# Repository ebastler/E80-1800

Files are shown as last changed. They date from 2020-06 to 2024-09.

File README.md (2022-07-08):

# E80-1800
QMK compatible USB-C PCB for a Cherry G80-1800

The board has been prototyped and works as intended, while fitting most G80-1800 housings. Rev 1.1 and later should fix all tolerance issues, and fit all G80-1800 (and as far as I know also G81-1800) enclosures. I can, however, not guarantee perfect operation of the PCB or compatibility with every enclosure variation - if you encounter any issues, please let me know. Rev 1.2 has not yet been tested, but changes were minimal - no issues are to be expected. Stock situations as well as component rotations at JLC may change over time and hence I can not guarantee for the BOM/CPL files to work perfectly. Please double-check before ordering!

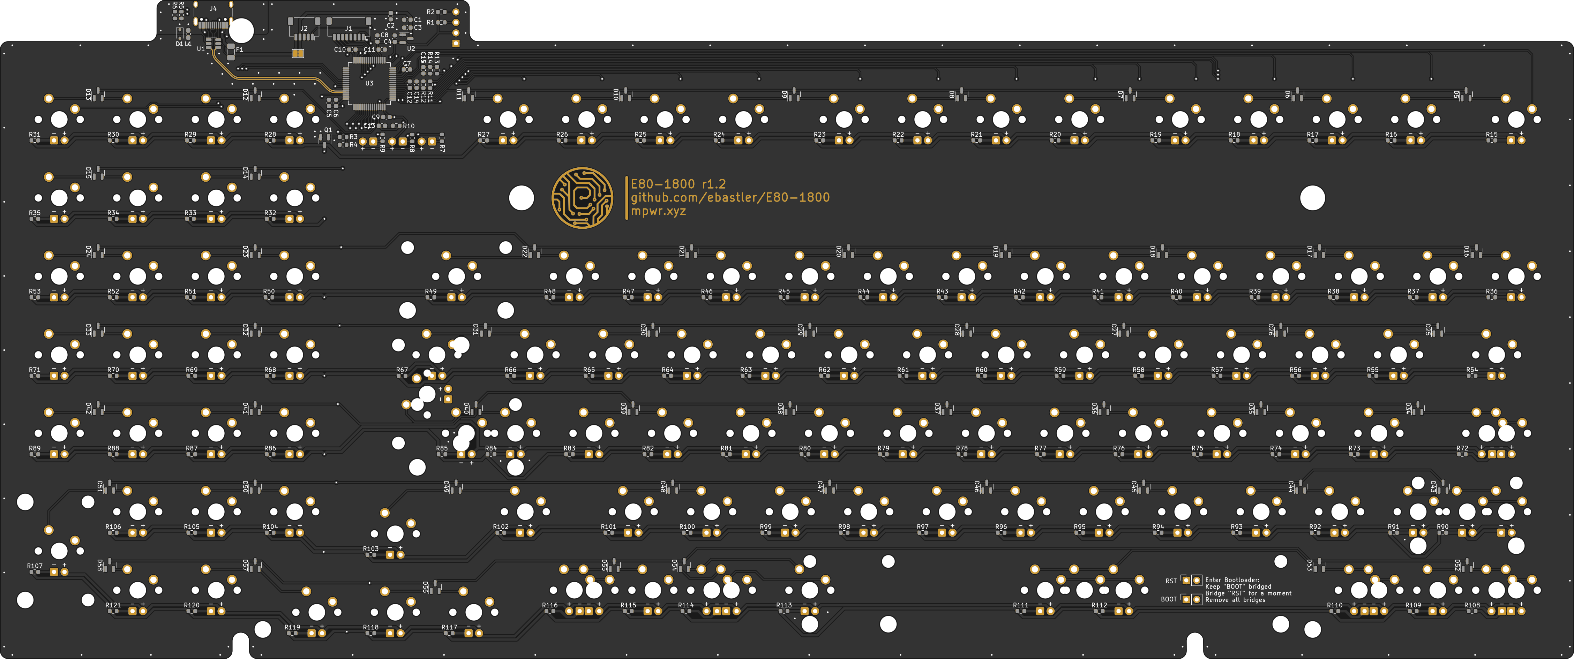
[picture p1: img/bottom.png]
pcb_bottom
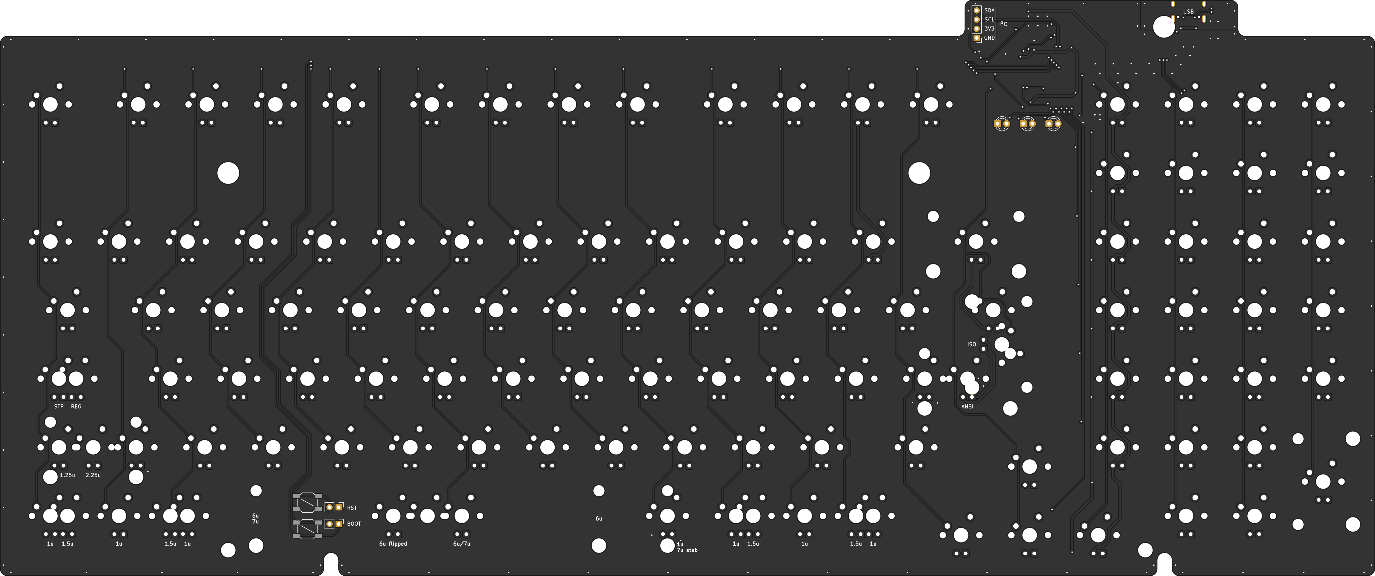
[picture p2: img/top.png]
pcb_top
|||
|:---:|:---:|

## Order information at JLCPCB
All relevant files can be found in `E80-1800-pcb-universal\jlcpcb`. The `gerber` subfolder contains a .zip file, the `assembly` subfolder contains the BOM and POS/CPL files needed for assembly. Please double-check all component values and rotations before ordering!

* [gerber](E80-1800-pcb-universal/jlcpcb/gerber/GERBER-E80-1800-pcb-universal.zip)
* [BOM](E80-1800-pcb-universal/jlcpcb/assembly/BOM-E80-1800-pcb-universal.csv)
* [POS](E80-1800-pcb-universal/jlcpcb/assembly/POS-E80-1800-pcb-universal.csv)

Since jlcpcb usually fails to auto-determine the PCB dimensions: `382 x 160 mm` is the correct size.

Consider donating me a few bucks if you order boards :)

## Features
 - USB-C (you have to widen the cable hole in the case with a file or similar)
 - Full ESD protection
 - Future-proof STM32F072 with QMK
 - Optional I²C OLED screen in the card-reader-hole on card-reader G80-1800 models
 - SPI header for Bluetooth LE - software support may or may not follow (currently not supported by QMK). The SPI pads can also be used for other expansions such as adding a Solenoid or RGB stripe.
 - Header to connect an optional battery management daughterboard
 - Single color dimmable backlight (3mm LEDs)
 - Silkscreen labels for LED polarity and multi-layout options for easier assembly

The board is fully supported by the QMK master branch: https://github.com/qmk/qmk_firmware/tree/master/keyboards/ebastler/e80_1800
A VIA compatible JSON file can be found in the "VIA" folder of this repo, and the PCB is also fully supported by https://remap-keys.app

## Supported layouts
The PCB was designed to support all layout options G80-1800 and G81-1800 were originally available in. I did not include layout options that go beyond those on purpose, since overlapping switch holes lead to wobbly switches (remember, the G80 boards are plateless!) which diminishes the typing experience. 
 - Full ISO and ANSI support
 - 1 - 1 - 1 - 6 - 1 - 1 - 1 - 1 bottom row (with flipped or regular spacebar)
 - 1.5 - 1.5 - 7 - 1.5 - 1.5 bottom row
 - Stepped and regular caps lock

## Thanks to
 - [Evy](https://github.com/evyd13) for supplying me with her [GH80-1800 drop in replacement PCB](https://geekhack.org/index.php?topic=96692.0) layout, which I could use for dimensions and measurements - saved me a lot of time! Even if I ended up redrawing the dimensions from scratch and changing a few, being able to use his as a starting point was a lot of help.
 - SMOKEY for motivating me once I lost the will to continue with the project
 - MarvFPV for helping me with the physical PCB dimensions and supplying me with valuable ideas
 - Zitres for organizing and shipping a small-batch closed GB together with me that led to a lot of satisfied users

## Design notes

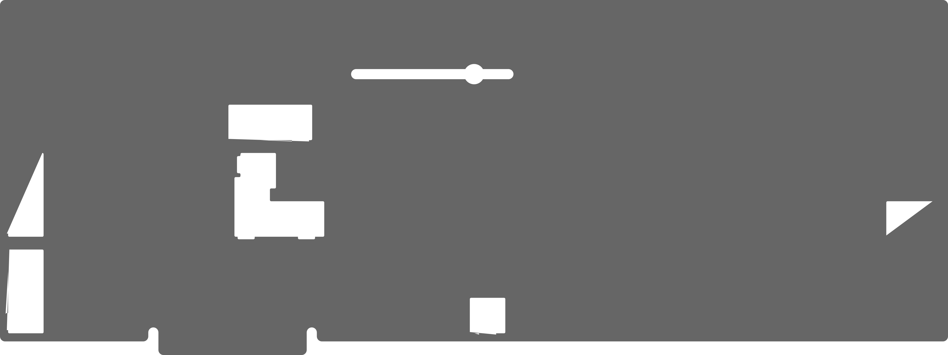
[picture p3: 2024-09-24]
E80-1800-plate-universal/fab/E80-1800-plate-universal-.bottom.png

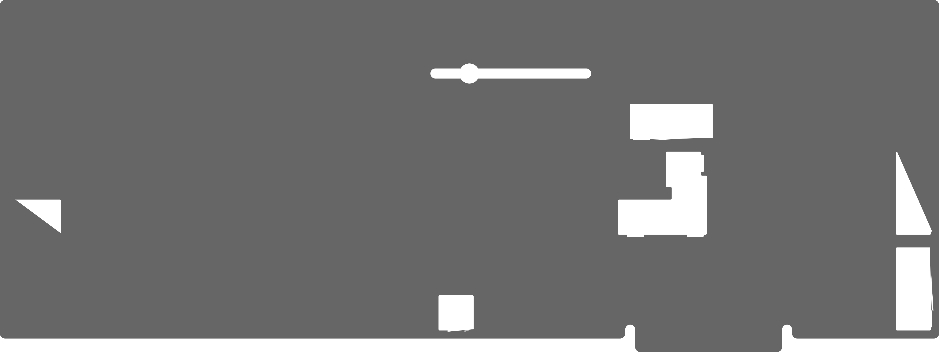
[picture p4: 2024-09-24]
E80-1800-plate-universal/fab/E80-1800-plate-universal-.top.png

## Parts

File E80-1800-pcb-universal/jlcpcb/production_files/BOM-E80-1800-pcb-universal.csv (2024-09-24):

Comment | Designator | Footprint | LCSC
PBY160808T-181Y-N | L1 | L_0603_1608Metric_Pad1.05x0.95mm_HandSolder | C1002
100n | C10,C11,C12,C13,C14,C15,C6,C7,C9 | C_0603_1608Metric | C14663
1206L050 | F1 | Fuse_1206_3216Metric | C151162
BSD3C051V | D1 | D_SOD-323 | C151996
1u | C3,C4 | C_0603_1608Metric | C15849
USB_C_Receptacle_USB2.0 | J4 | USB_C_Receptacle_HRO_TYPE-C-31-M-12 | C165948
4u7 | C1,C2,C5,C8 | C_0603_1608Metric | C19666
Q_NMOS_GSD | Q1 | SOT-23 | C20917
1k | R7,R8,R9 | R_0603_1608Metric | C21190
100R | R3 | R_0603_1608Metric | C22775
4k7 | R1,R2 | R_0603_1608Metric | C23162
5k1 | R5,R6 | R_0603_1608Metric | C23186
560 | R100,R101,R102,R103,R104,R105,R106,R107,R108,R109,R110,R111,R112,R113,R114,R115,R116,R117,R118,R119,R120,R121,R15,R16,R17,R18,R19,R20,R21,R22,R23,R24,R25,R26,R27,R28,R29,R30,R31,R32,R33,R34,R35,R36,R37,R38,R39,R40,R41,R42,R43,R44,R45,R46,R47,R48,R49,R50,R51,R52,R53,R54,R55,R56,R57,R58,R59,R60,R61,R62,R63,R64,R65,R66,R67,R68,R69,R70,R71,R72,R73,R74,R75,R76,R77,R78,R79,R80,R81,R82,R83,R84,R85,R86,R87,R88,R89,R90,R91,R92,R93,R94,R95,R96,R97,R98,R99 | R_0603_1608Metric | C23204
10k | R10,R4 | R_0603_1608Metric | C25804
47k | R11,R12,R13,R14 | R_0603_1608Metric | C25819
STM32F072RBTx | U3 | LQFP-64_10x10mm_P0.5mm | C46046
XC6206P332MR | U2 | SOT-23 | C5446
BAV70 | D10,D11,D12,D13,D14,D15,D16,D17,D18,D19,D20,D21,D22,D23,D24,D25,D26,D27,D28,D29,D30,D31,D32,D33,D34,D35,D36,D37,D38,D39,D40,D41,D42,D43,D44,D45,D46,D47,D48,D49,D5,D50,D51,D52,D53,D54,D55,D56,D57,D58,D6,D7,D8,D9 | SOT-23 | C68978
SRV05-4 | U1 | SOT-23-6-routable | C85364
RST | SW1 | SW_SPST_SKQG_WithStem
BOOT | SW2 | SW_SPST_SKQG_WithStem

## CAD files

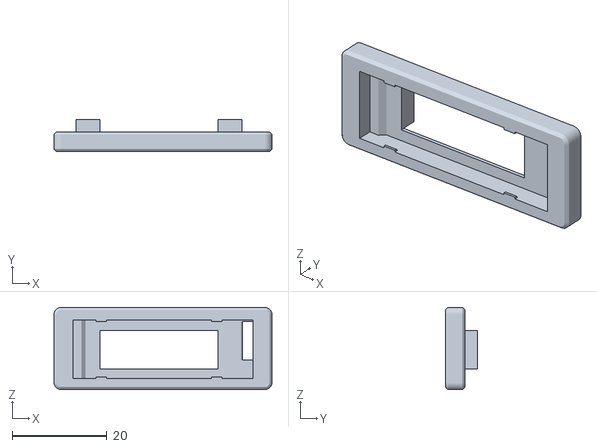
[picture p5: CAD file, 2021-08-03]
cardreader-inserts/oled-blocker.stl
46.0 x 6.72 x 17.3

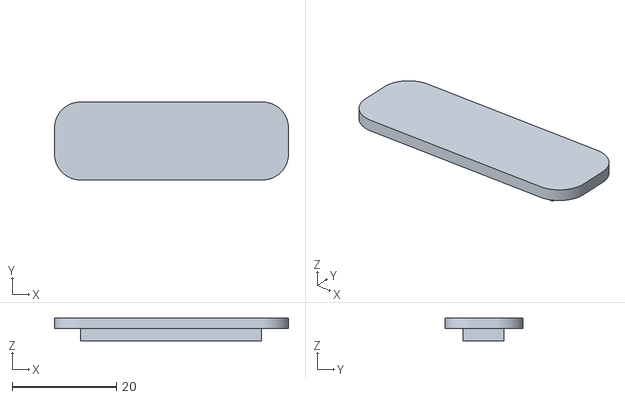
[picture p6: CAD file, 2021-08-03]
cardreader-inserts/closed-blocker.stl
45.0 x 15.0 x 4.40

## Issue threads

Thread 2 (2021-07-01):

Interest

o0-o, 2021-07-01:
Hey, I'm interested in this project but have no experience with custom pcbs. Are you planning on having a run of these manufactured? Is that up to someone else? Can I take these plans to someone and have a one-off made? Is it still considered work-in-progress and or is it production-ready?

Would love to get my hands on one. Thanks for all the work on it.

ebastler, 2021-07-03:
Hey!

I was (and still am) planning to get a batch manufcatured and sell them - Covid and the following chip crysis however hit the market really hard, there's currently no chance to get a reasonable amount (even 1 is already hard) of the chips on this PCB for a decent price (less than 10-20 bucks per chip, they should be ~ 1.5$ MSRP).

Once the market recovers, I'm definitely still planning to do a Groupbuy!

o0-o, 2021-07-05:
That's great! What can I follow/subscribe/check to be sure I'm notified once you start taking pre-orders?

Also, what would it take to add a split backspace option to the board? I use all compact boards and my muscle memory has the backspace on R2 so I make a lot of \\\\\\ typos on this board. I'd be happy to sponsor that feature if you're open to it (and I can afford it).

ebastler, 2021-07-09:
I'm currently thinking about creating a discord server, not sure if I'll do that though. My instagram (nick: ebastler) should be useful, if you have instagram. Guess I'll make it a geekhack post too.

ebastler, 2022-01-29:
In case anyone stumbles upon this: https://discord.gg/VG8xeKzdr7
I actually made a discord server.

Closed 2022-01-29.

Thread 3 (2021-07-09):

6U space centered or offset switch?

o0-o, 2021-07-09:
My G80-1800 has an offset 6U spacebar which is very uncommon in keysets that are produced today. Will this board accommodate the much more common centered 6U?

ebastler, 2021-07-09:
Hi, it accepts only 6u offcenter and 7u. The PCB was designed around OG cherry sets, and I had to keep compatibility to a minimum so that I do not have overlapping switches, which increase switch wobble/risk of soldering them crookedly by a lot on a plateless design.

I can see if I get the centered switch squeezed in, but not sure if that'l work out. I thought that 6u offcenter was the more common one to be honest.

o0-o, 2021-07-10:
Yeah now that I'm looking back through key sets, I'm seeing mostly sets that have both 6U options (when they have any at all), some have a single option that isn't labelled and of course the one that I have ([BIIP](https://drop.com/buy/drop-biip-mt3-extended-custom-keycap-set)) only has a centered one. So if centered 6u is more common, it is only slightly so.

I have a 7U space and can live with that. I see your point about the stability of the pcb-mounted switches. I haven't worked on a pcb-mount board in years so I forgot about the caveats.

Closed 2021-07-10.

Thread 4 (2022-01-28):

QMK Firmware

spooknik, 2022-01-28:
Hello! I noticed the [link ](https://github.com/ebastler/qmk_firmware/tree/E80_1800/keyboards/ebastler/E80_1800)in the readme for the QMK firmware links to a missing repo. I also couldn't find the firmware in the official QMK repo.

Do you have happen to still have the firmware?

Thanks & have a nice weekend 👍

P.s. I forked the PCB and modified it to accept a [64X128 OLED](https://www.aliexpress.com/item/4001028369082.html?spm=a2g0o.9042311.0.0.5a554c4d7qBFis). I think it will just fit where status LEDs are on a stock 1800 case. Requires that part of the case to be removed of course.

ebastler, 2022-01-29:
Hi! Here you go:
https://github.com/ebastler/qmk_firmware/tree/E80_1800/keyboards/ebastler/e80_1800

I think I changed the folder name from E80 to e80, to comply with QMK guidelines. Forgot to update the repo over here accordingly.

the VIA keymap compiles and works fine, the bongocat keymap is broken and I didn't find the time to get the animation running. But you'll make your own animation stuff anyway since you're using a 64x128px screen, I guess. Very curious how it will look with a screen instead of the indicators!

Closed 2022-01-29.

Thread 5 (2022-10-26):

[GUIDE]Flash the E80-1800(STM32F07)

geekofrosty, 2022-10-26:
This is my first time flash the STM32,with the ebastler E80-1800
but the author`s guide is very simple
after learned how to flash it and succeed,
I record the progress for newb or anyone make the ebastler E80 may need it

Platform: Windows 11 22H2 ver 22621.674
Build Environment:[QMK MSYS](https://msys.qmk.fm/) ver 1.72
Flash Software: [QMK Toolbox](https://github.com/qmk/qmk_toolbox) ver 0.2.2
My MCU:STM32F072RBT6

### 1. Install [QMK Toolbox](https://github.com/qmk/qmk_toolbox)
After installed QMK Toolbox,you have to install the drivers in the "Tools" menu
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

### 2. Connect the keyboard to PC
According to the [author`s guide](https://github.com/qmk/qmk_firmware/tree/master/keyboards/ebastler/e80_1800)

> No pre-flashed firmware, option 1: Bridge BOOT labeled pads below spacebar while plugging the board in

then in the QMK Toolbox you will see STM32 Bootloader connect in yellow font
and in the Device Manager there will be a new device named "STM32 BOOTLOADER"

### 3.Install [QMK MSYS](https://msys.qmk.fm/) and build environment

> See the [build environment setup](https://docs.qmk.fm/#/getting_started_build_tools)

Do a test to verify the environment,in the QMK MSYS window,input the command:
`$ qmk compile -kb lets_split -km default`
successfully you will see a lot of [OK] in green font

### 4.Compile the E80-1800 firmware
Input the command in the QMK MSYS window:
`$ qmk compile -kb ebastler/E80-1800 -km default`
you will get 4 files in your C:\Users\<username>\qmk_firmware\.build
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

### 5.Flash the firmware
Back to the QMK Toolbox
Press the open button and select the file: ebastler_e80_1800_default.bin, not the .hex file
MCU drop down leave it default or select the ATmega32U4
And press "Flash"

This step according to the [[Guide] Flashing Planck Rev6 or STM32 PCB on Windows](https://www.reddit.com/r/olkb/comments/a9gf47/guide_flashing_planck_rev6_or_stm32_pcb_on_windows/)

Finsh!

PS.My english is not good,hope you can read it and success!

o0-o, 2022-10-26:
Did I miss the group buy or how did you get one?

emrebag, 2023-12-29:
Any reason we have to compile on our own pc?
Plenty of PCBs come with hex files and they all work fine

emrebag, 2023-12-29:
Noting this here so I can prevent someone like myself from spending three hours for nothing:
JUST FLASH THE VIA BIN
https://www.caniusevia.com/docs/download_firmware

ebastler, 2023-12-30:
Thanks github for only notifying me about this issue today. I have never received a mail until now, for whatever reason.

The guide is - mostly - correct, but this line `$ qmk compile -kb ebastler/e80-1800 -km default` needs a lowercase e, unlike what OP posted.

I did not see the necessity to add any guides myself - it is a QMK board, and QMK developers made their own very extensive documentation. Rewriting or copy-pasting it over here felt pointless to me: https://wsl.qmk.fm/guide.html

For compiling at home, I would recommend QMK-WSL over MSYS by now, less effort to set up and better performance.

On my discord server there is pre-compiled firmwares for it (default with OLED animation, VIA, VIAwith OLED animation). On the VIA download page, as indicated below, there is downloads available as well (only "base" VIA firmware, but updated more frequently than my downloads on discord).

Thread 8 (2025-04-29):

The files are gone

Snajj, 2025-04-29:
Gerber and BOM links redirect to 404 error not found page.

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

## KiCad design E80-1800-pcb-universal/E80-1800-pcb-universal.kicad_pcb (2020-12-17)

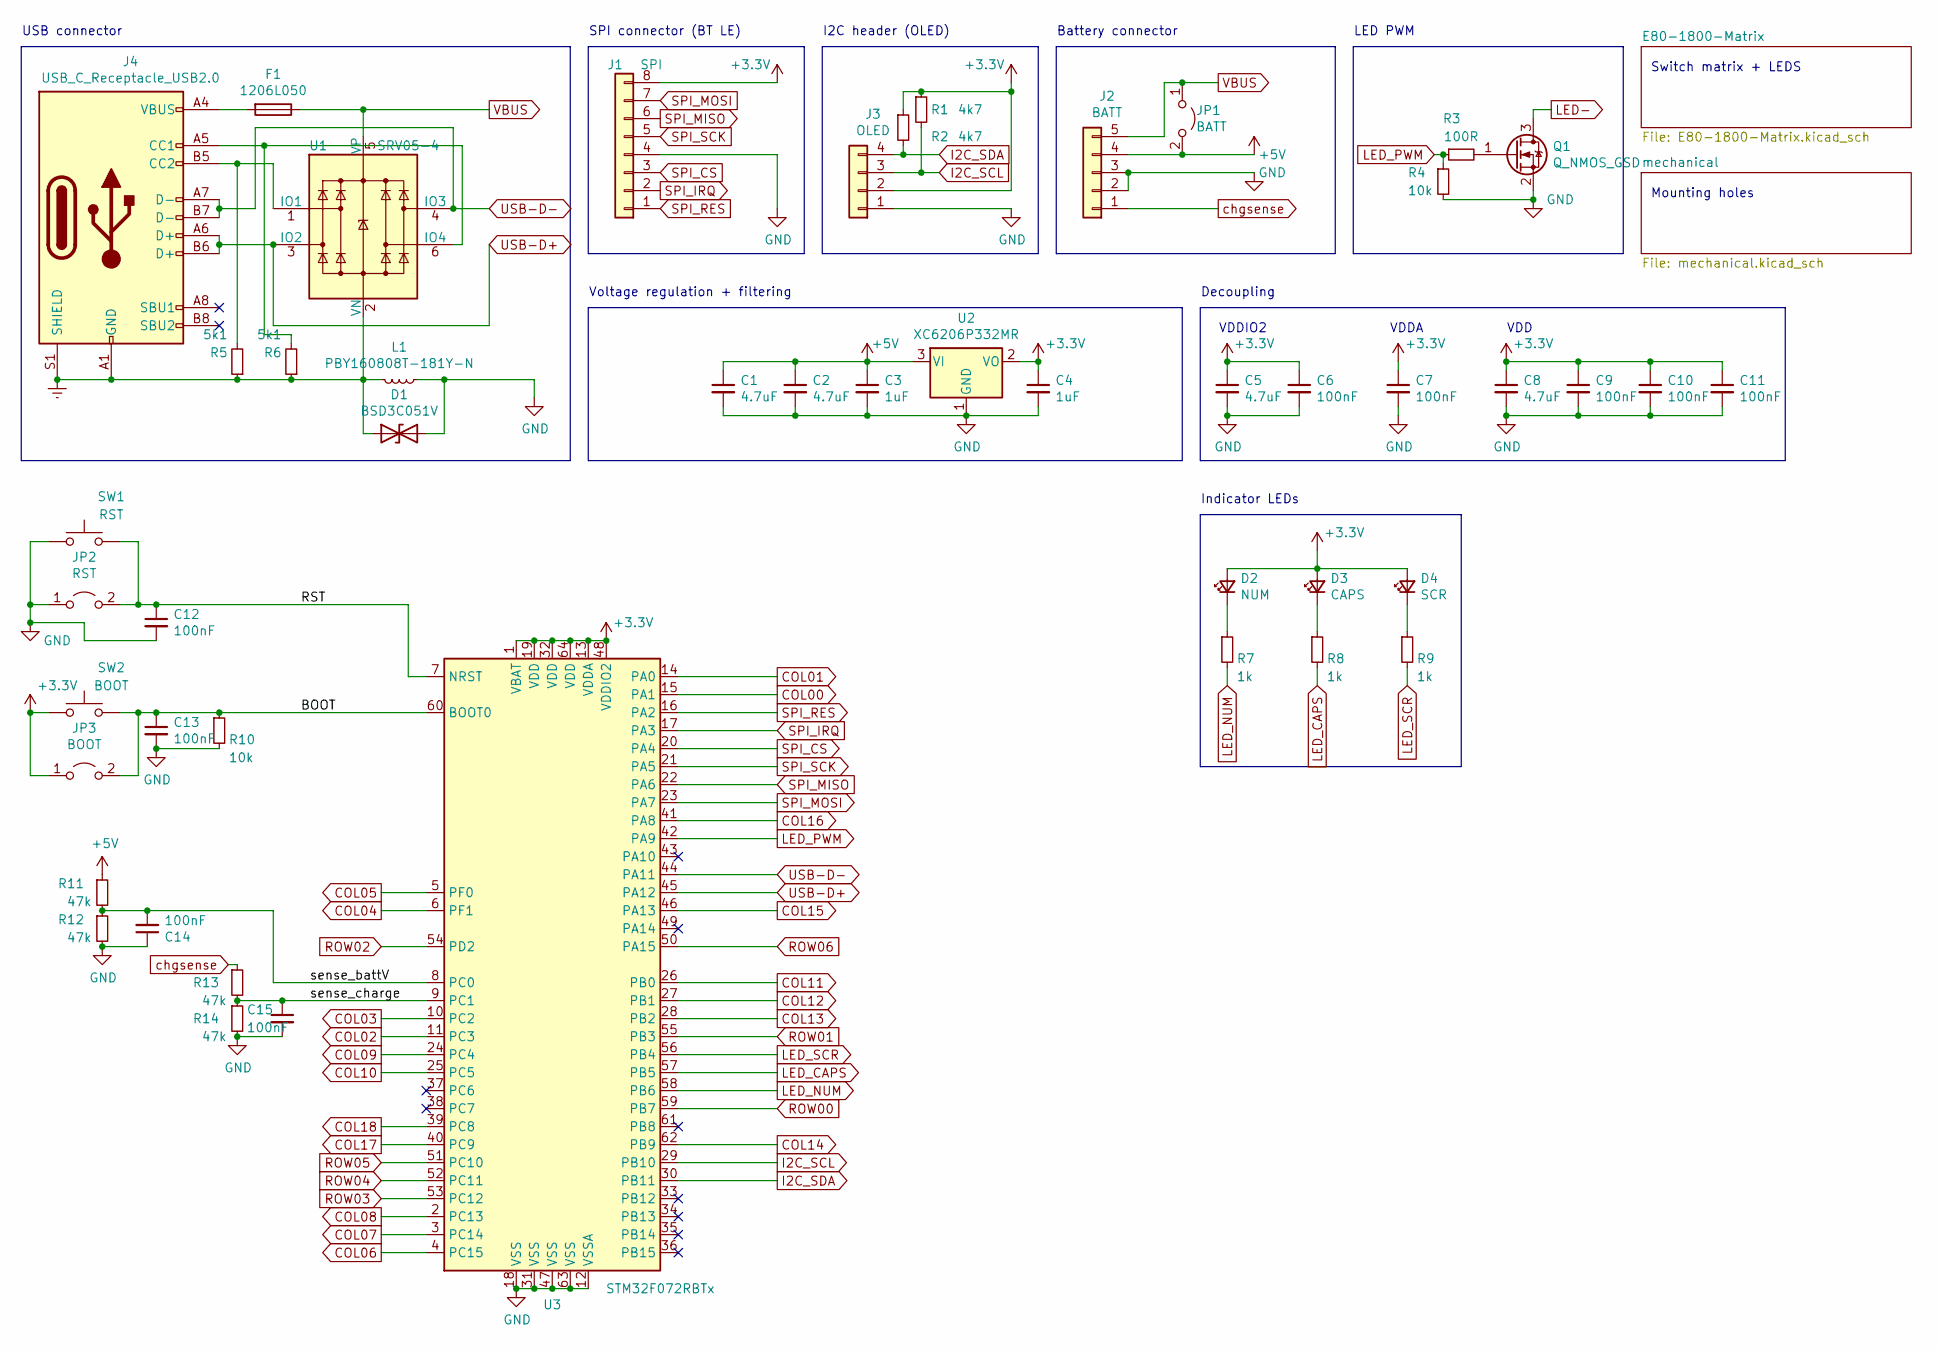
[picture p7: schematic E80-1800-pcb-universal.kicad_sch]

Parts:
C1, C2, C5, C8: 4.7uF; C_0603_1608Metric; LCSC C19666
C3, C4: 1uF; C_0603_1608Metric; LCSC C15849
C6, C7, C9, C10, C11, C12, C13, C14, C15: 100nF; C_0603_1608Metric; LCSC C14663
D1: BSD3C051V; D_SOD-323; LCSC C151996
D2: NUM; LED_D3.0mm
D3: CAPS; LED_D3.0mm
D4: SCR; LED_D3.0mm
F1: 1206L050; Fuse_1206_3216Metric; LCSC C151162
J1: SPI; JST_SH_SM08B-SRSS-TB_1x08-1MP_P1.00mm_Horizontal
J2: BATT; JST_SH_SM05B-SRSS-TB_1x05-1MP_P1.00mm_Horizontal
J3: OLED; PinHeader_1x04_P2.54mm_Vertical
J4: USB_C_Receptacle_USB2.0; USB_C_Receptacle_HRO_TYPE-C-31-M-12; LCSC C165948
JP1: BATT; SolderJumper-2_P1.3mm_Bridged2Bar_Pad1.0x1.5mm
JP2: RST; PinHeader_1x02_P2.54mm_Vertical
JP3: BOOT; PinHeader_1x02_P2.54mm_Vertical
L1: PBY160808T-181Y-N; L_0603_1608Metric_Pad1.05x0.95mm_HandSolder; LCSC C114288
Q1: Q_NMOS_GSD; SOT-23; LCSC C20917
R1, R2: 4k7; R_0603_1608Metric; LCSC C23162
R3: 100R; R_0603_1608Metric; LCSC C22775
R4, R10: 10k; R_0603_1608Metric; LCSC C25804
R5, R6: 5k1; R_0603_1608Metric; LCSC C23186
R7, R8, R9: 1k; R_0603_1608Metric; LCSC C21190
R11, R12, R13, R14: 47k; R_0603_1608Metric; LCSC C25819
SW1: RST; SW_SPST_SKQG_WithoutStem
SW2: BOOT; SW_SPST_SKQG_WithoutStem
U1: SRV05-4; SOT-23-6; LCSC C85364
U2: XC6206P332MR; SOT-23; LCSC C5446
U3: STM32F072RBTx; LQFP-64_10x10mm_P0.5mm; LCSC C46046

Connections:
COL00: U3.15 (PA1); also elsewhere on the board
COL01: U3.14 (PA0); also elsewhere on the board
COL02: U3.11 (PC3); also elsewhere on the board
COL03: U3.10 (PC2); also elsewhere on the board
COL04: U3.6 (PF1); also elsewhere on the board
COL05: U3.5 (PF0); also elsewhere on the board
COL06: U3.4 (PC15); also elsewhere on the board
COL07: U3.3 (PC14); also elsewhere on the board
COL08: U3.2 (PC13); also elsewhere on the board
COL09: U3.24 (PC4); also elsewhere on the board
COL10: U3.25 (PC5); also elsewhere on the board
COL11: U3.26 (PB0); also elsewhere on the board
COL12: U3.27 (PB1); also elsewhere on the board
COL13: U3.28 (PB2); also elsewhere on the board
COL14: U3.62 (PB9); also elsewhere on the board
COL15: U3.46 (PA13); also elsewhere on the board
COL16: U3.41 (PA8); also elsewhere on the board
COL17: U3.40 (PC9); also elsewhere on the board
COL18: U3.39 (PC8); also elsewhere on the board
Earth: D1.1 (A1), J4.A1 (GND), J4.A12 (GND), J4.B1 (GND), J4.B12 (GND), J4.S1 (SHIELD), L1.2, R5.1, R6.1, U1.2 (VN)
I2C_SCL: J3.3, R1.2, U3.29 (PB10)
I2C_SDA: J3.4, R2.2, U3.30 (PB11)
LED-: Q1.3 (D); also elsewhere on the board
LED_CAPS: R8.2, U3.57 (PB5)
LED_NUM: R7.2, U3.58 (PB6)
LED_PWM: R3.1, R4.1, U3.42 (PA9)
LED_SCR: R9.2, U3.56 (PB4)
unnamed: D2.1 (K), R7.1
unnamed: D3.1 (K), R8.1
unnamed: D4.1 (K), R9.1
unnamed: F1.2, J4.A4 (VBUS), J4.A9 (VBUS), J4.B4 (VBUS), J4.B9 (VBUS)
unnamed: J4.A5 (CC1), R6.2, U1.6 (IO4)
unnamed: J4.B5 (CC2), R5.2, U1.1 (IO1)
unnamed: Q1.1 (G), R3.2
ROW00: U3.59 (PB7); also elsewhere on the board
ROW01: U3.55 (PB3); also elsewhere on the board
ROW02: U3.54 (PD2); also elsewhere on the board
ROW03: U3.53 (PC12); also elsewhere on the board
ROW04: U3.52 (PC11); also elsewhere on the board
ROW05: U3.51 (PC10); also elsewhere on the board
ROW06: U3.50 (PA15); also elsewhere on the board
SPI_CS: J1.3, U3.20 (PA4)
SPI_IRQ: J1.2, U3.17 (PA3)
SPI_MISO: J1.6, U3.22 (PA6)
SPI_MOSI: J1.7, U3.23 (PA7)
SPI_RES: J1.1, U3.16 (PA2)
SPI_SCK: J1.5, U3.21 (PA5)
USB-D+: J4.A6 (D+), J4.B6 (D+), U1.3 (IO2), U3.45 (PA12)
USB-D-: J4.A7 (D-), J4.B7 (D-), U1.4 (IO3), U3.44 (PA11)
VBUS: F1.1, J2.5, JP1.1 (A), U1.5 (VP)
chgsense: J2.1, R13.1

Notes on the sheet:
Mounting holes
LED PWM
VDDA
SPI connector (BT LE)
VDD
USB connector
I2C header (OLED)
VDDIO2
Indicator LEDs
Voltage regulation + filtering
Switch matrix + LEDS
Decoupling
Battery connector

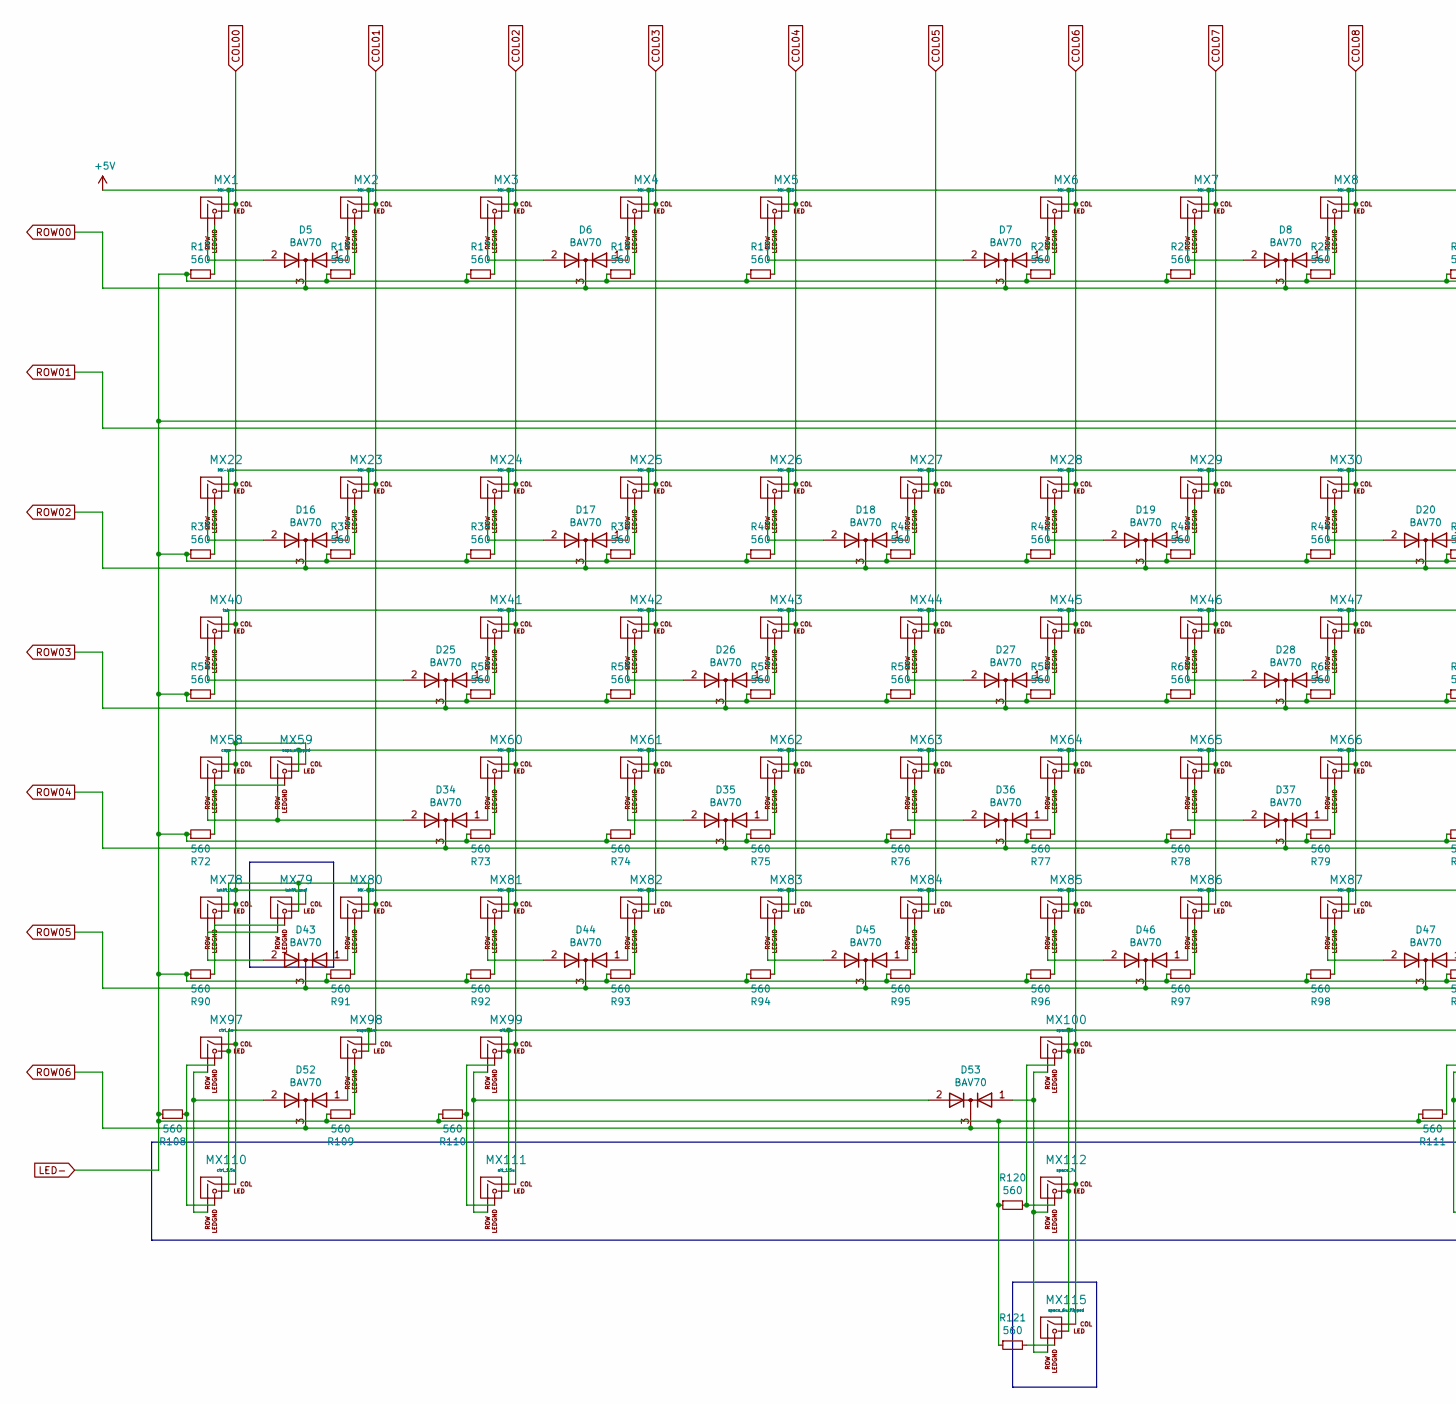
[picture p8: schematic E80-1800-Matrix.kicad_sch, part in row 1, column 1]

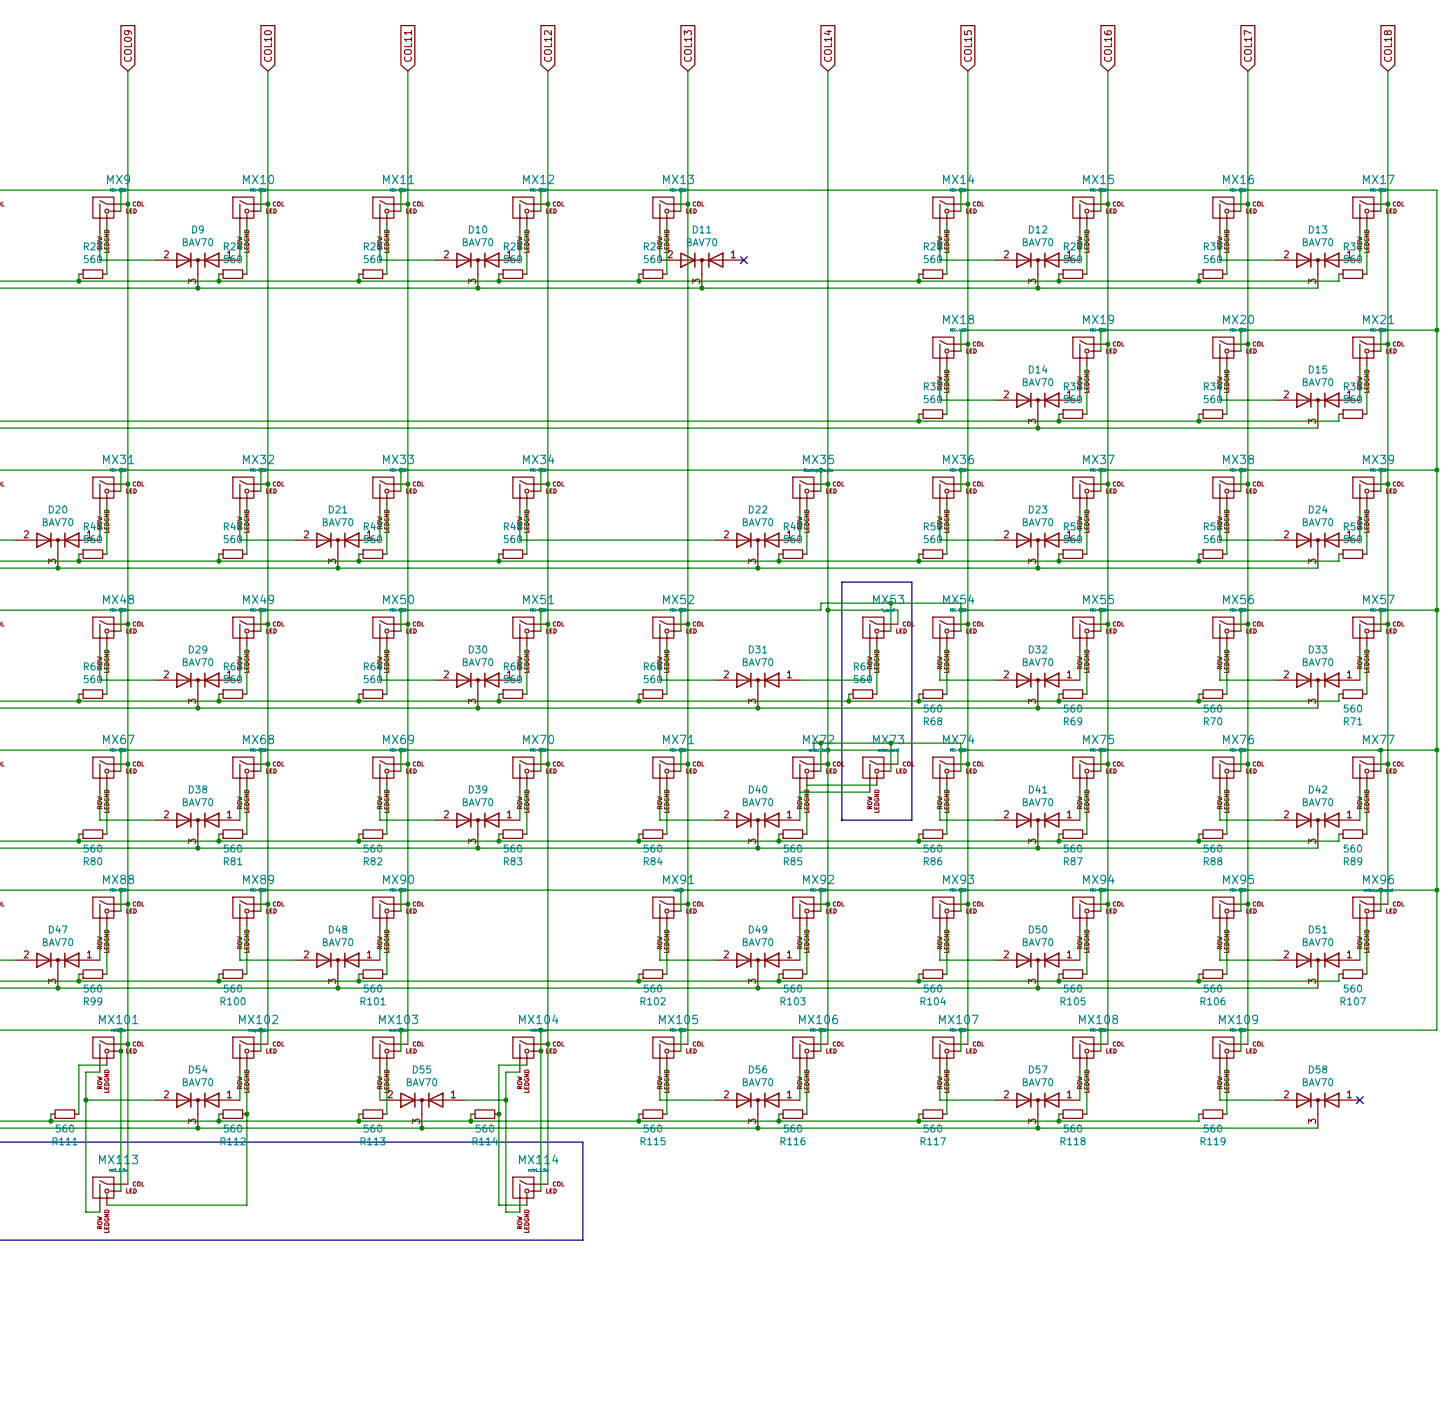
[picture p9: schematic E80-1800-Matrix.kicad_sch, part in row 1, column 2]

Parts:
D5, D6, D7, D8, D9, D10, D11, D12, D13, D14, D15, D16, D17, D18, D19, D20, D21, D22, D23, D24, D25, D26, D27, D28, D29, D30, D31, D32, D33, D34, D35, D36, D37, D38, D39, D40, D41, D42, D43, D44, D45, D46, D47, D48, D49, D50, D51, D52, D53, D54, D55, D56, D57, D58: BAV70; SOT-23; LCSC C68978
MX1, MX2, MX3, MX4, MX5, MX6, MX7, MX8, MX9, MX10, MX11, MX12, MX13, MX14, MX15, MX16, MX17, MX18, MX19, MX20, MX21, MX22, MX23, MX24, MX25, MX26, MX27, MX28, MX29, MX30, MX31, MX32, MX33, MX34, MX36, MX37, MX38, MX39, MX41, MX42, MX43, MX44, MX45, MX46, MX47, MX48, MX49, MX50, MX51, MX52, MX54, MX55, MX56, MX57, MX60, MX61, MX62, MX63, MX64, MX65, MX66, MX67, MX68, MX69, MX70, MX71, MX74, MX75, MX76, MX80, MX81, MX82, MX83, MX84, MX85, MX86, MX87, MX88, MX89, MX90, MX92, MX93, MX94, MX95, MX105, MX106, MX107, MX108, MX109: MX-LED; MXOnly-1U
MX35: Backspace_2u; MXOnly-2U
MX40: tab; MXOnly-1.5U
MX53: \_ansi; MXOnly-1.5U
MX58: caps; MXOnly-1.75U-FLIPPED
MX59: caps_stepped; MXOnly-1.25U
MX72: enter_iso; MXOnly-ISO-ROTATED-ReversedStabilizers
MX73: enter_ansi; MXOnly-2.25U
MX77: +; MXOnly-1U
MX78: lshift_iso; MXOnly-1.25U
MX79: lshift_ansi; MXOnly-2.25U
MX91: rshift; MXOnly-1.75U
MX96: enter_numpad; MXOnly-ISO
MX97: ctrl_1u; MXOnly-1U
MX98: super_1u; MXOnly-1U
MX99: alt_1u; MXOnly-1U-FLIPPED
MX100: space_6u; MXOnly-6U
MX101: ralt_1u; MXOnly-1U
MX102: rsuper_1u; MXOnly-1U
MX103: menu_1u; MXOnly-1U
MX104: rctrl_1u; MXOnly-1U-FLIPPED
MX110: ctrl_1.5u; MXOnly-1.5U-FLIPPED
MX111: alt_1.5u; MXOnly-1.5U
MX112: space_7u; MXOnly-7U
MX113: ralt_1.5u; MXOnly-1.5U-FLIPPED
MX114: rctrl_1.5u; MXOnly-1.5U
MX115: space_6u_flipped; MXOnly-1U
R15, R16, R17, R18, R19, R20, R21, R22, R23, R24, R25, R26, R27, R28, R29, R30, R31, R32, R33, R34, R35, R36, R37, R38, R39, R40, R41, R42, R43, R44, R45, R46, R47, R48, R49, R50, R51, R52, R53, R54, R55, R56, R57, R58, R59, R60, R61, R62, R63, R64, R65, R66, R67, R68, R69, R70, R71, R72, R73, R74, R75, R76, R77, R78, R79, R80, R81, R82, R83, R84, R85, R86, R87, R88, R89, R90, R91, R92, R93, R94, R95, R96, R97, R98, R99, R100, R101, R102, R103, R104, R105, R106, R107, R108, R109, R110, R111, R112, R113, R114, R115, R116, R117, R118, R119, R120, R121: 560; R_0603_1608Metric; LCSC C23204

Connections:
COL00: MX1.1 (COL), MX22.1 (COL), MX40.1 (COL), MX58.1 (COL), MX59.1 (COL), MX78.1 (COL), MX79.1 (COL), MX97.1 (COL), MX110.1 (COL); also elsewhere on the board
COL01: MX2.1 (COL), MX23.1 (COL), MX80.1 (COL), MX98.1 (COL); also elsewhere on the board
COL02: MX3.1 (COL), MX24.1 (COL), MX41.1 (COL), MX60.1 (COL), MX81.1 (COL), MX99.1 (COL), MX111.1 (COL); also elsewhere on the board
COL03: MX4.1 (COL), MX25.1 (COL), MX42.1 (COL), MX61.1 (COL), MX82.1 (COL); also elsewhere on the board
COL04: MX5.1 (COL), MX26.1 (COL), MX43.1 (COL), MX62.1 (COL), MX83.1 (COL); also elsewhere on the board
COL05: MX27.1 (COL), MX44.1 (COL), MX63.1 (COL), MX84.1 (COL); also elsewhere on the board
COL06: MX6.1 (COL), MX28.1 (COL), MX45.1 (COL), MX64.1 (COL), MX85.1 (COL), MX100.1 (COL), MX112.1 (COL), MX115.1 (COL); also elsewhere on the board
COL07: MX7.1 (COL), MX29.1 (COL), MX46.1 (COL), MX65.1 (COL), MX86.1 (COL); also elsewhere on the board
COL08: MX8.1 (COL), MX30.1 (COL), MX47.1 (COL), MX66.1 (COL), MX87.1 (COL); also elsewhere on the board
COL09: MX9.1 (COL), MX31.1 (COL), MX48.1 (COL), MX67.1 (COL), MX88.1 (COL), MX101.1 (COL), MX113.1 (COL); also elsewhere on the board
COL10: MX10.1 (COL), MX32.1 (COL), MX49.1 (COL), MX68.1 (COL), MX89.1 (COL), MX102.1 (COL); also elsewhere on the board
COL11: MX11.1 (COL), MX33.1 (COL), MX50.1 (COL), MX69.1 (COL), MX90.1 (COL), MX103.1 (COL); also elsewhere on the board
COL12: MX12.1 (COL), MX34.1 (COL), MX51.1 (COL), MX70.1 (COL), MX104.1 (COL), MX114.1 (COL); also elsewhere on the board
COL13: MX13.1 (COL), MX52.1 (COL), MX71.1 (COL), MX91.1 (COL), MX105.1 (COL); also elsewhere on the board
COL14: MX35.1 (COL), MX53.1 (COL), MX72.1 (COL), MX73.1 (COL), MX92.1 (COL), MX106.1 (COL); also elsewhere on the board
COL15: MX14.1 (COL), MX18.1 (COL), MX36.1 (COL), MX54.1 (COL), MX74.1 (COL), MX93.1 (COL), MX107.1 (COL); also elsewhere on the board
COL16: MX15.1 (COL), MX19.1 (COL), MX37.1 (COL), MX55.1 (COL), MX75.1 (COL), MX94.1 (COL), MX108.1 (COL); also elsewhere on the board
COL17: MX16.1 (COL), MX20.1 (COL), MX38.1 (COL), MX56.1 (COL), MX76.1 (COL), MX95.1 (COL), MX109.1 (COL); also elsewhere on the board
COL18: MX17.1 (COL), MX21.1 (COL), MX39.1 (COL), MX57.1 (COL), MX77.1 (COL), MX96.1 (COL); also elsewhere on the board
LED-: R15.1, R16.1, R17.1, R18.1, R19.1, R20.1, R21.1, R22.1, R23.1, R24.1, R25.1, R26.1, R27.1, R28.1, R29.1, R30.1, R31.1, R32.1, R33.1, R34.1, R35.1, R36.1, R37.1, R38.1, R39.1, R40.1, R41.1, R42.1, R43.1, R44.1, R45.1, R46.1, R47.1, R48.1, R49.1, R50.1, R51.1, R52.1, R53.1, R54.1, R55.1, R56.1, R57.1, R58.1, R59.1, R60.1, R61.1, R62.1, R63.1, R64.1, R65.1, R66.1, R67.1, R68.1, R69.1, R70.1, R71.1, R72.1, R73.1, R74.1, R75.1, R76.1, R77.1, R78.1, R79.1, R80.1, R81.1, R82.1, R83.1, R84.1, R85.1, R86.1, R87.1, R88.1, R89.1, R90.1, R91.1, R92.1, R93.1, R94.1, R95.1, R96.1, R97.1, R98.1, R99.1, R100.1, R101.1, R102.1, R103.1, R104.1, R105.1, R106.1, R107.1, R108.1, R109.1, R110.1, R111.1, R112.1, R113.1, R114.1, R115.1, R116.1, R117.1, R118.1, R119.1, R120.1, R121.1; also elsewhere on the board
unnamed: D5.1 (A), MX2.2 (ROW)
unnamed: D5.2 (A), MX1.2 (ROW)
unnamed: D6.1 (A), MX4.2 (ROW)
unnamed: D6.2 (A), MX3.2 (ROW)
unnamed: D7.1 (A), MX6.2 (ROW)
unnamed: D7.2 (A), MX5.2 (ROW)
unnamed: D8.1 (A), MX8.2 (ROW)
unnamed: D8.2 (A), MX7.2 (ROW)
unnamed: D9.1 (A), MX10.2 (ROW)
unnamed: D9.2 (A), MX9.2 (ROW)
unnamed: D10.1 (A), MX12.2 (ROW)
unnamed: D10.2 (A), MX11.2 (ROW)
unnamed: D11.2 (A), MX13.2 (ROW)
unnamed: D12.1 (A), MX15.2 (ROW)
unnamed: D12.2 (A), MX14.2 (ROW)
unnamed: D13.1 (A), MX17.2 (ROW)
unnamed: D13.2 (A), MX16.2 (ROW)
unnamed: D14.1 (A), MX19.2 (ROW)
unnamed: D14.2 (A), MX18.2 (ROW)
unnamed: D15.1 (A), MX21.2 (ROW)
unnamed: D15.2 (A), MX20.2 (ROW)
unnamed: D16.1 (A), MX23.2 (ROW)
unnamed: D16.2 (A), MX22.2 (ROW)
unnamed: D17.1 (A), MX25.2 (ROW)
unnamed: D17.2 (A), MX24.2 (ROW)
unnamed: D18.1 (A), MX27.2 (ROW)
unnamed: D18.2 (A), MX26.2 (ROW)
unnamed: D19.1 (A), MX29.2 (ROW)
unnamed: D19.2 (A), MX28.2 (ROW)
unnamed: D20.1 (A), MX31.2 (ROW)
unnamed: D20.2 (A), MX30.2 (ROW)
unnamed: D21.1 (A), MX33.2 (ROW)
unnamed: D21.2 (A), MX32.2 (ROW)
unnamed: D22.1 (A), MX35.2 (ROW)
unnamed: D22.2 (A), MX34.2 (ROW)
unnamed: D23.1 (A), MX37.2 (ROW)
unnamed: D23.2 (A), MX36.2 (ROW)
unnamed: D24.1 (A), MX39.2 (ROW)
unnamed: D24.2 (A), MX38.2 (ROW)
unnamed: D25.1 (A), MX41.2 (ROW)
unnamed: D25.2 (A), MX40.2 (ROW)
unnamed: D26.1 (A), MX43.2 (ROW)
unnamed: D26.2 (A), MX42.2 (ROW)
unnamed: D27.1 (A), MX45.2 (ROW)
unnamed: D27.2 (A), MX44.2 (ROW)
unnamed: D28.1 (A), MX47.2 (ROW)
unnamed: D28.2 (A), MX46.2 (ROW)
unnamed: D29.1 (A), MX49.2 (ROW)
unnamed: D29.2 (A), MX48.2 (ROW)
unnamed: D30.1 (A), MX51.2 (ROW)
unnamed: D30.2 (A), MX50.2 (ROW)
unnamed: D31.1 (A), MX53.2 (ROW)
unnamed: D31.2 (A), MX52.2 (ROW)
unnamed: D32.1 (A), MX55.2 (ROW)
unnamed: D32.2 (A), MX54.2 (ROW)
unnamed: D33.1 (A), MX57.2 (ROW)
unnamed: D33.2 (A), MX56.2 (ROW)
unnamed: D34.1 (A), MX60.2 (ROW)
unnamed: D34.2 (A), MX58.2 (ROW), MX59.2 (ROW)
unnamed: D35.1 (A), MX62.2 (ROW)
unnamed: D35.2 (A), MX61.2 (ROW)
unnamed: D36.1 (A), MX64.2 (ROW)
unnamed: D36.2 (A), MX63.2 (ROW)
unnamed: D37.1 (A), MX66.2 (ROW)
unnamed: D37.2 (A), MX65.2 (ROW)
unnamed: D38.1 (A), MX68.2 (ROW)
unnamed: D38.2 (A), MX67.2 (ROW)
unnamed: D39.1 (A), MX70.2 (ROW)
unnamed: D39.2 (A), MX69.2 (ROW)
unnamed: D40.1 (A), MX72.2 (ROW), MX73.2 (ROW)
unnamed: D40.2 (A), MX71.2 (ROW)
unnamed: D41.1 (A), MX75.2 (ROW)
unnamed: D41.2 (A), MX74.2 (ROW)
unnamed: D42.1 (A), MX77.2 (ROW)
unnamed: D42.2 (A), MX76.2 (ROW)
unnamed: D43.1 (A), MX80.2 (ROW)
unnamed: D43.2 (A), MX78.2 (ROW), MX79.2 (ROW)
unnamed: D44.1 (A), MX82.2 (ROW)
unnamed: D44.2 (A), MX81.2 (ROW)
unnamed: D45.1 (A), MX84.2 (ROW)
unnamed: D45.2 (A), MX83.2 (ROW)
unnamed: D46.1 (A), MX86.2 (ROW)
unnamed: D46.2 (A), MX85.2 (ROW)
unnamed: D47.1 (A), MX88.2 (ROW)
unnamed: D47.2 (A), MX87.2 (ROW)
unnamed: D48.1 (A), MX90.2 (ROW)
unnamed: D48.2 (A), MX89.2 (ROW)
unnamed: D49.1 (A), MX92.2 (ROW)
unnamed: D49.2 (A), MX91.2 (ROW)
unnamed: D50.1 (A), MX94.2 (ROW)
unnamed: D50.2 (A), MX93.2 (ROW)
unnamed: D51.1 (A), MX96.2 (ROW)
unnamed: D51.2 (A), MX95.2 (ROW)
unnamed: D52.1 (A), MX98.2 (ROW)
unnamed: D52.2 (A), MX97.2 (ROW), MX110.2 (ROW)
unnamed: D53.1 (A), MX100.2 (ROW), MX112.2 (ROW), MX115.2 (ROW)
unnamed: D53.2 (A), MX99.2 (ROW), MX111.2 (ROW)
unnamed: D54.1 (A), MX102.2 (ROW)
unnamed: D54.2 (A), MX101.2 (ROW), MX113.2 (ROW)
unnamed: D55.1 (A), MX104.2 (ROW), MX114.2 (ROW)
unnamed: D55.2 (A), MX103.2 (ROW)
unnamed: D56.1 (A), MX106.2 (ROW)
unnamed: D56.2 (A), MX105.2 (ROW)
unnamed: D57.1 (A), MX108.2 (ROW)
unnamed: D57.2 (A), MX107.2 (ROW)
unnamed: D58.2 (A), MX109.2 (ROW)
unnamed: MX1.4 (LEDGND), R15.2
unnamed: MX2.4 (LEDGND), R16.2
unnamed: MX3.4 (LEDGND), R17.2
unnamed: MX4.4 (LEDGND), R18.2
unnamed: MX5.4 (LEDGND), R19.2
unnamed: MX6.4 (LEDGND), R20.2
unnamed: MX7.4 (LEDGND), R21.2
unnamed: MX8.4 (LEDGND), R22.2
unnamed: MX9.4 (LEDGND), R23.2
unnamed: MX10.4 (LEDGND), R24.2
unnamed: MX11.4 (LEDGND), R25.2
unnamed: MX12.4 (LEDGND), R26.2
unnamed: MX13.4 (LEDGND), R27.2
unnamed: MX14.4 (LEDGND), R28.2
unnamed: MX15.4 (LEDGND), R29.2
unnamed: MX16.4 (LEDGND), R30.2
unnamed: MX17.4 (LEDGND), R31.2
unnamed: MX18.4 (LEDGND), R32.2
unnamed: MX19.4 (LEDGND), R33.2
unnamed: MX20.4 (LEDGND), R34.2
unnamed: MX21.4 (LEDGND), R35.2
unnamed: MX22.4 (LEDGND), R36.2
unnamed: MX23.4 (LEDGND), R37.2
unnamed: MX24.4 (LEDGND), R38.2
unnamed: MX25.4 (LEDGND), R39.2
unnamed: MX26.4 (LEDGND), R40.2
unnamed: MX27.4 (LEDGND), R41.2
unnamed: MX28.4 (LEDGND), R42.2
unnamed: MX29.4 (LEDGND), R43.2
unnamed: MX30.4 (LEDGND), R44.2
unnamed: MX31.4 (LEDGND), R45.2
unnamed: MX32.4 (LEDGND), R46.2
unnamed: MX33.4 (LEDGND), R47.2
unnamed: MX34.4 (LEDGND), R48.2
unnamed: MX35.4 (LEDGND), R49.2
unnamed: MX36.4 (LEDGND), R50.2
unnamed: MX37.4 (LEDGND), R51.2
unnamed: MX38.4 (LEDGND), R52.2
unnamed: MX39.4 (LEDGND), R53.2
unnamed: MX40.4 (LEDGND), R54.2
unnamed: MX41.4 (LEDGND), R55.2
unnamed: MX42.4 (LEDGND), R56.2
unnamed: MX43.4 (LEDGND), R57.2
unnamed: MX44.4 (LEDGND), R58.2
unnamed: MX45.4 (LEDGND), R59.2
unnamed: MX46.4 (LEDGND), R60.2
unnamed: MX47.4 (LEDGND), R61.2
unnamed: MX48.4 (LEDGND), R62.2
unnamed: MX49.4 (LEDGND), R63.2
unnamed: MX50.4 (LEDGND), R64.2
unnamed: MX51.4 (LEDGND), R65.2
unnamed: MX52.4 (LEDGND), R66.2
unnamed: MX53.4 (LEDGND), R67.2
unnamed: MX54.4 (LEDGND), R68.2
unnamed: MX55.4 (LEDGND), R69.2
unnamed: MX56.4 (LEDGND), R70.2
unnamed: MX57.4 (LEDGND), R71.2
unnamed: MX58.4 (LEDGND), MX59.4 (LEDGND), R72.2
unnamed: MX60.4 (LEDGND), R73.2
unnamed: MX61.4 (LEDGND), R74.2
unnamed: MX62.4 (LEDGND), R75.2
unnamed: MX63.4 (LEDGND), R76.2
unnamed: MX64.4 (LEDGND), R77.2
unnamed: MX65.4 (LEDGND), R78.2
unnamed: MX66.4 (LEDGND), R79.2
unnamed: MX67.4 (LEDGND), R80.2
unnamed: MX68.4 (LEDGND), R81.2
unnamed: MX69.4 (LEDGND), R82.2
unnamed: MX70.4 (LEDGND), R83.2
unnamed: MX71.4 (LEDGND), R84.2
unnamed: MX72.4 (LEDGND), MX73.4 (LEDGND), R85.2
unnamed: MX74.4 (LEDGND), R86.2
unnamed: MX75.4 (LEDGND), R87.2
unnamed: MX76.4 (LEDGND), R88.2
unnamed: MX77.4 (LEDGND), R89.2
unnamed: MX78.4 (LEDGND), MX79.4 (LEDGND), R90.2
unnamed: MX80.4 (LEDGND), R91.2
unnamed: MX81.4 (LEDGND), R92.2
unnamed: MX82.4 (LEDGND), R93.2
unnamed: MX83.4 (LEDGND), R94.2
unnamed: MX84.4 (LEDGND), R95.2
unnamed: MX85.4 (LEDGND), R96.2
unnamed: MX86.4 (LEDGND), R97.2
unnamed: MX87.4 (LEDGND), R98.2
unnamed: MX88.4 (LEDGND), R99.2
unnamed: MX89.4 (LEDGND), R100.2
unnamed: MX90.4 (LEDGND), R101.2
unnamed: MX91.4 (LEDGND), R102.2
unnamed: MX92.4 (LEDGND), R103.2
unnamed: MX93.4 (LEDGND), R104.2
unnamed: MX94.4 (LEDGND), R105.2
unnamed: MX95.4 (LEDGND), R106.2
unnamed: MX96.4 (LEDGND), R107.2
unnamed: MX98.4 (LEDGND), R109.2
unnamed: MX100.4 (LEDGND), MX112.4 (LEDGND), R120.2
unnamed: MX101.4 (LEDGND), R111.2
unnamed: MX102.4 (LEDGND), MX113.4 (LEDGND), R112.2
unnamed: MX103.4 (LEDGND), R113.2
unnamed: MX104.4 (LEDGND), MX114.4 (LEDGND), R114.2
unnamed: MX105.4 (LEDGND), R115.2
unnamed: MX106.4 (LEDGND), R116.2
unnamed: MX107.4 (LEDGND), R117.2
unnamed: MX108.4 (LEDGND), R118.2
unnamed: MX109.4 (LEDGND), R119.2
unnamed: MX97.4 (LEDGND), MX110.4 (LEDGND), R108.2
unnamed: MX99.4 (LEDGND), MX111.4 (LEDGND), R110.2
unnamed: MX115.4 (LEDGND), R121.2
ROW00: D5.3 (K), D6.3 (K), D7.3 (K), D8.3 (K), D9.3 (K), D10.3 (K), D11.3 (K), D12.3 (K), D13.3 (K); also elsewhere on the board
ROW01: D14.3 (K), D15.3 (K); also elsewhere on the board
ROW02: D16.3 (K), D17.3 (K), D18.3 (K), D19.3 (K), D20.3 (K), D21.3 (K), D22.3 (K), D23.3 (K), D24.3 (K); also elsewhere on the board
ROW03: D25.3 (K), D26.3 (K), D27.3 (K), D28.3 (K), D29.3 (K), D30.3 (K), D31.3 (K), D32.3 (K), D33.3 (K); also elsewhere on the board
ROW04: D34.3 (K), D35.3 (K), D36.3 (K), D37.3 (K), D38.3 (K), D39.3 (K), D40.3 (K), D41.3 (K), D42.3 (K); also elsewhere on the board
ROW05: D43.3 (K), D44.3 (K), D45.3 (K), D46.3 (K), D47.3 (K), D48.3 (K), D49.3 (K), D50.3 (K), D51.3 (K); also elsewhere on the board
ROW06: D52.3 (K), D53.3 (K), D54.3 (K), D55.3 (K), D56.3 (K), D57.3 (K), D58.3 (K); also elsewhere on the board

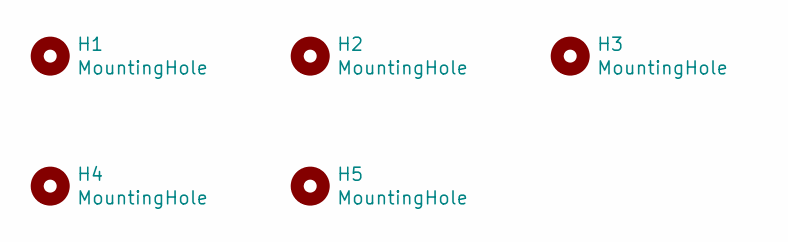
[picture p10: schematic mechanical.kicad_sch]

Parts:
H1, H2, H3: MountingHole; MountingHole_6mm
H4, H5: MountingHole; MountingHole_4mm

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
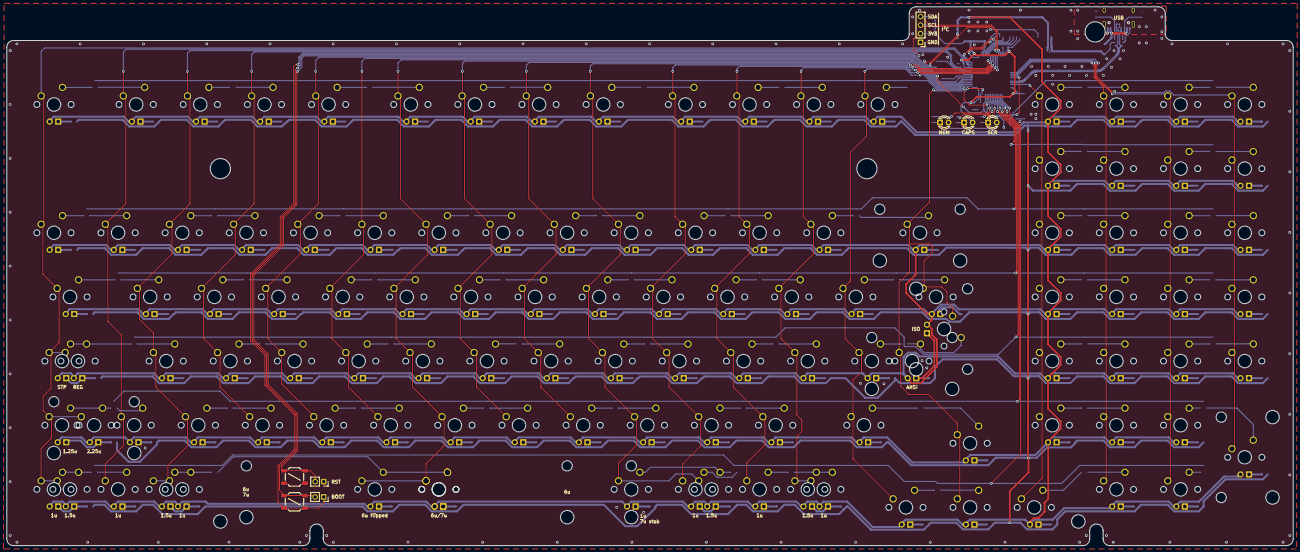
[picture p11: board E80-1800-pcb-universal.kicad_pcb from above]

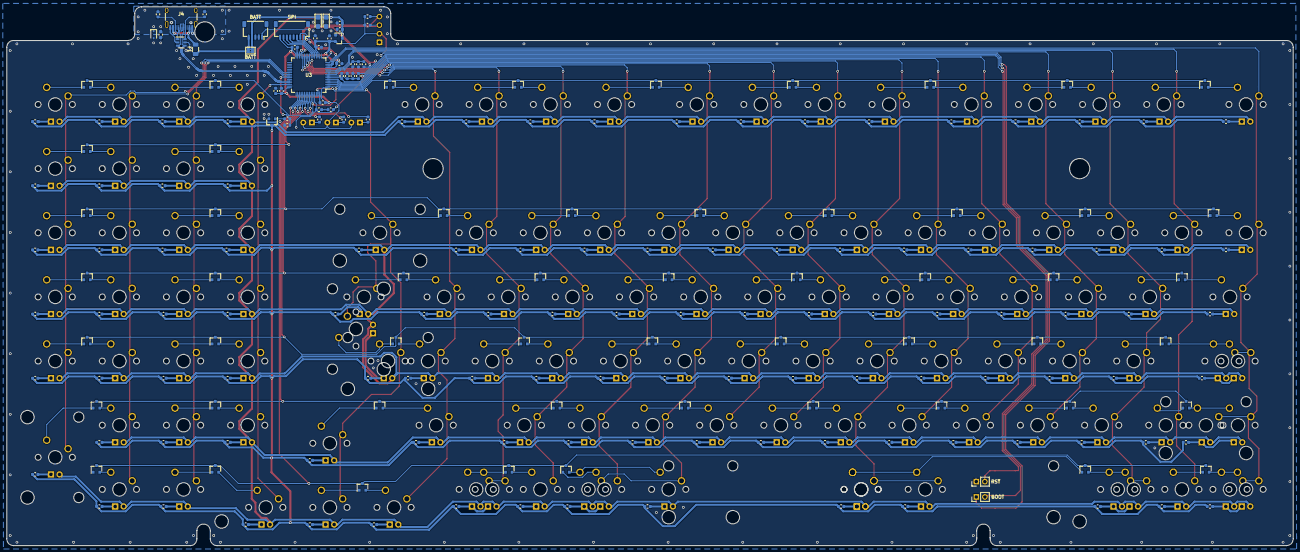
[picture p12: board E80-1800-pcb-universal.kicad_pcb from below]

Board: 2 copper layers, 382.0 x 160.0 mm, 330 parts (204 on the bottom side), 271 nets.

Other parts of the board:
C16: 100nF; C_0603_1608Metric_stealth

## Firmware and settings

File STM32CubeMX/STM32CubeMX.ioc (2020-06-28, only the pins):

Mcu.UserName=STM32F072RBTx
PA11.Signal=USB_DM
PA12.Signal=USB_DP
PA2.Signal=GPIO_Output
PA3.Signal=GPIO_Output
PA4.Signal=GPIO_Output
PA5.Signal=SPI1_SCK
PA6.Signal=SPI1_MISO
PA7.Signal=SPI1_MOSI
PA8.Signal=S_TIM1_CH1
PB6.Signal=I2C1_SCL
PB7.Signal=I2C1_SDA
PC0.Signal=ADC_IN10
PC1.Signal=ADC_IN11

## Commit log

2020-05-25 added libs to kicad
2020-06-28 created PCB
    [E80-1800-Matrix.sch, mechanical.sch]
2020-06-28 wired up remaining cols
    [E80-1800-pcb-universal.kicad_pcb, E80-1800-pcb-universal.sch]
2020-06-29 added huge silkscreen pads for "white" front on green pcbs
    [E80-1800-pcb-universal.kicad_pcb]
2020-06-29 temporary gerbers to check on silkscreen
    [E80-1800-pcb-universal-B_Cu.gbr, E80-1800-pcb-universal-B_Mask.gbr, E80-1800-pcb-universal-B_Paste.gbr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]
2020-06-30 continued routing
    [E80-1800-pcb-universal.kicad_pcb, E80-1800-pcb-universal.sch]
2020-07-04 finished pcb layout, added silk labels
    [E80-1800-Matrix.sch, E80-1800-pcb-universal.kicad_pcb, E80-1800-pcb-universal.sch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]
2020-07-04 deleted temporary gerbers
    [E80-1800-pcb-universal-B_Cu.gbr, E80-1800-pcb-universal-B_Mask.gbr, E80-1800-pcb-universal-B_Paste.gbr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]
2020-07-04 added jlc gerbers + smt files
    [E80-1800-pcb-universal-B_Cu.gbr, E80-1800-pcb-universal-B_Mask.gbr, E80-1800-pcb-universal-B_Paste.gbr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]
2020-07-20 added real pictures of pcb
2020-08-31 improved mounting holes
    [E80-1800-Matrix.sch, E80-1800-pcb-universal.kicad_pcb, E80-1800-pcb-universal.sch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]
2020-08-31 minor routing changes
    [E80-1800-Matrix.sch, E80-1800-pcb-universal.kicad_pcb, E80-1800-pcb-universal.sch]
2020-09-20 cosmethic changes
    [E80-1800-pcb-universal.kicad_pcb]
2020-09-22 added logo submodule
    [E80-1800-pcb-universal.kicad_pcb]
2020-09-22 added logo
    [E80-1800-pcb-universal.kicad_pcb]
2020-09-22 increased readability, added missing cap
    [E80-1800-Matrix.sch, E80-1800-pcb-universal.sch]
2020-09-22 minor routing improvements, added missing cap
    [E80-1800-pcb-universal.kicad_pcb]
2020-09-22 moved 4u7 to a better spot
    [E80-1800-pcb-universal.kicad_pcb, E80-1800-pcb-universal.sch]
2020-09-22 re-added logo
    [E80-1800-pcb-universal.kicad_pcb]
2020-09-22 removed wrongly placed sch text
    [E80-1800-Matrix.sch, E80-1800-pcb-universal.sch]
2020-09-22 removed unneeded 3d model
    [E80-1800-pcb-universal.kicad_pcb]
2020-09-22 moved graphics
    [E80-1800-pcb-universal.kicad_pcb]
2020-10-04 added TVS for ESD prot
    [E80-1800-Matrix.sch, E80-1800-pcb-universal.sch]
2020-10-04 minor routing changes, exposed copper for usb traces, added TVS
    [E80-1800-pcb-universal.kicad_pcb]
2020-10-04 swapped parts to fit jlc stocks
    [E80-1800-pcb-universal.kicad_pcb, E80-1800-pcb-universal.sch]
2020-10-04 added new jlc fab files
    [E80-1800-pcb-universal-B_Cu.gbr, E80-1800-pcb-universal-B_Mask.gbr, E80-1800-pcb-universal-B_Paste.gbr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]
2020-10-04 some kicad files
2020-10-04 added pcb renders
2020-12-17 updated submodules
    [E80-1800-pcb-universal.kicad_pcb]
2021-03-11 updated kicad cpl/bom to match current stocks, cleaned some unneeded files
    [E80-1800-pcb-universal.sch, E80-1800-pcb-universal_bom_jlc.csv, mechanical.sch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]
2022-01-12 updated to kc6.0 files, minor improvements, new jlcpcb files
    [E80-1800-Matrix.kicad_sch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]
2022-01-12 replaced pcb renders
2022-01-12 fixed bom/cpl
2022-07-08 updated to v1.2 (switch to marbastlib)
    [E80-1800-Matrix.kicad_sch, E80-1800-Matrix.sch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]
2022-07-08 fixed gitignore not to exclude BOM/CPL anymore
    [BOM-E80-1800-pcb-universal.csv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]
2022-07-08 fixed gerber path
2022-08-12 corrected rotations after jlcpcb seems to have messed up their entire lib
    [POS-E80-1800-pcb-universal.csv]
2024-09-24 update to PCM marbastlib and KC8
    [E80-1800-Matrix.kicad_sch, E80-1800-pcb-universal.kicad_sch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]
2024-09-24 updated jlc production files to current stocks, fixed rotations, moved symbols to PCB marbastlib
    [BOM-E80-1800-pcb-universal.csv, E80-1800-Matrix.kicad_sch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]
